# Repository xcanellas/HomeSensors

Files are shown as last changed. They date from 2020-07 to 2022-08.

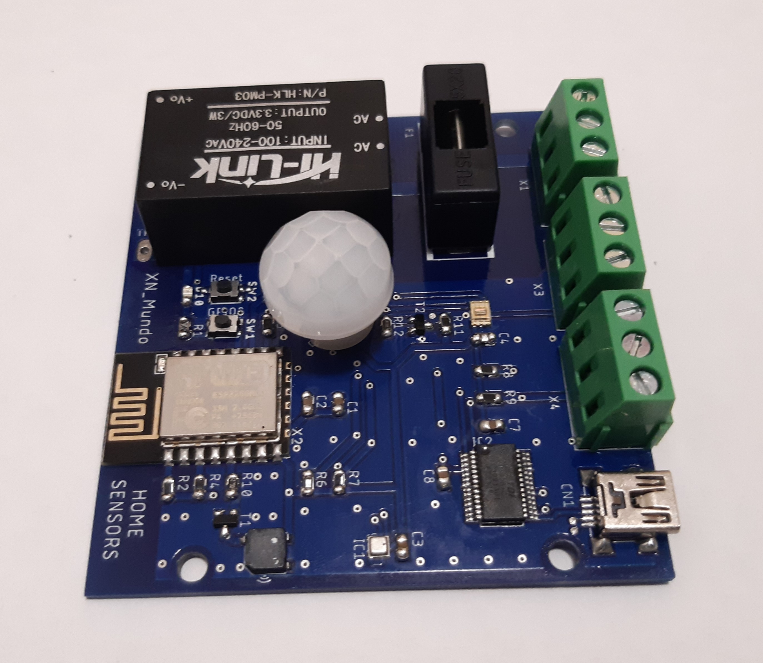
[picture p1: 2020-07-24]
Pictures/HomeSensors.jpg

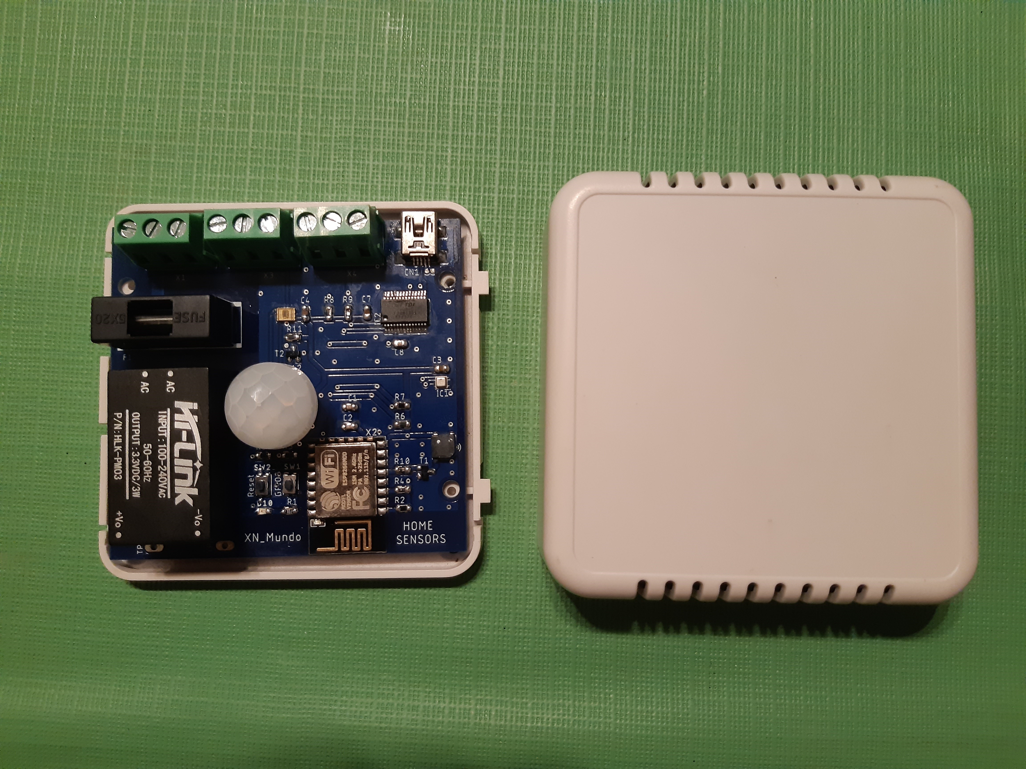
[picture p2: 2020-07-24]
Pictures/HomeSensorsBox.jpg

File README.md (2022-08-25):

## Descripción

Desarrollo de tarjeta electrónica para medir distintos sensores y enviar los datos a traves de WIFI a una base de datos para su posterior tratamiento y visualizacion via WEB.

## Autor
**Xavier Cañellas**

* [Linkedin] (https://www.linkedin.com/in/xcanellas/)
* [Proyectos personales] (http://xnmundo.com/)

## Contacto
Si quieres contactarme puedes escribirme a xcanellas@xnmundo.com para consultas.

## Lincencia
MIT Public License v3.0
No puede usarse comercialmente.

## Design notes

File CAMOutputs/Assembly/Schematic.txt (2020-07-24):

Partlist exported from C:/Users/xcane/Documents/EAGLE/projects/HomeSensors/Schematic.sch at 17/08/2019 17:57

Qty Value        Device                 Package                Parts                               Description                                                                                                                                                                                                                                INTERFACE MF MPN     OC_FARNELL OC_NEWARK SPICEPREFIX TP_SIGNAL_NAME
1                SH22                   SH22                   F1                                  FUSE HOLDER                                                                                                                                                                                                                                                     unknown    unknown                             
1                USBMINIB               USB-MINIB              CN1                                 USB Connectors                                                                                                                                                                                                                                                                                                 
3                W237-03P               W237-133               X1, X3, X4                          WAGO SREW CLAMP                                                                                                                                                                                                                                                 unknown    unknown                             
9   10k          R-EU_M0805             M0805                  R2, R3, R4, R5, R6, R7, R8, R9, R11 RESISTOR, European symbol                                                                                                                                                                                                                                                                                      
1   1k           R-EU_M0805             M0805                  R1                                  RESISTOR, European symbol                                                                                                                                                                                                                                                                                      
6   1uf          C-EUC0805              C0805                  C1, C2, C3, C4, C7, C8              CAPACITOR, European symbol                                                                                                                                                                                                                                                           C                         
1   270          R-EU_M0805             M0805                  R10                                 RESISTOR, European symbol                                                                                                                                                                                                                                                                                      
1   470          R-EU_M0805             M0805                  R12                                 RESISTOR, European symbol                                                                                                                                                                                                                                                                                      
2   BC847        BC847                  SOT23                  T1, T2                              NPN TRANSISTOR                                                                                                                                                                                                                                                                                                 
1   BME280       BME280                 BME280                 IC1                                 DIGITAL HUMIDITY, PRESSURE AND TEMPERATURE SENSOR* Digital interface I²C (up to 3.4 MHz) and SPI (3 and 4 wire, up to 10 MHz)* Supply voltage VDD main supply voltage range: 1.71 V to 3.6 V*VDDIO interface voltage range: 1.2 V to 3.6 V                                                                     
1   D203B        D203B                  3PIN                   PIR1                                                                                                                                                                                                                                                                                                                                               
1   ESP-12       ESP-12                 ESP-12                 X2                                                                                                                                                                                                                                                                                                                                                 
1   FT232RL      FT232RL                SSOP28                 IC2                                 Source: http://www.ftdichip.com/Documents/DataSheets/DS_FT232R_v104.pdf                                                                                                                                                                                 FT232RL 1146032    91K9918                             
1   HLK-PM013W   HLK-PM013W             HLK-PM01               HLK1                                Hi-Link Power Supply                                                                                                                                                                                                                                                                                           
2   KMR2         SWITCH_TACT_SMT4.6X2.8 BTN_KMR2_4.6X2.8       SW1, SW2                            SMT Tact Switches                                                                                                                                                                                                                                                                                              
1   RED          LED0805_NOOUTLINE      CHIPLED_0805_NOOUTLINE D10                                 LED                                                                                                                                                                                                                                                                                                            
1   SMT-0540-S-R SMT-0540-S-R           SMT-0540-S-R           SPK1                                SMT-0549-S-R                                                                                                                                                                                                                                                                                                   
2   TPSQPAD1-13Y TPSQPAD1-13Y           P1-13Y                 TP1, TP2                            Test pad                                                                                                                                                                                                                                                                                                       
1   TSL2561      TSL2561                TMB-6                  U1                                  Texas Instruments                                                                                                                                                                                                                          I2C

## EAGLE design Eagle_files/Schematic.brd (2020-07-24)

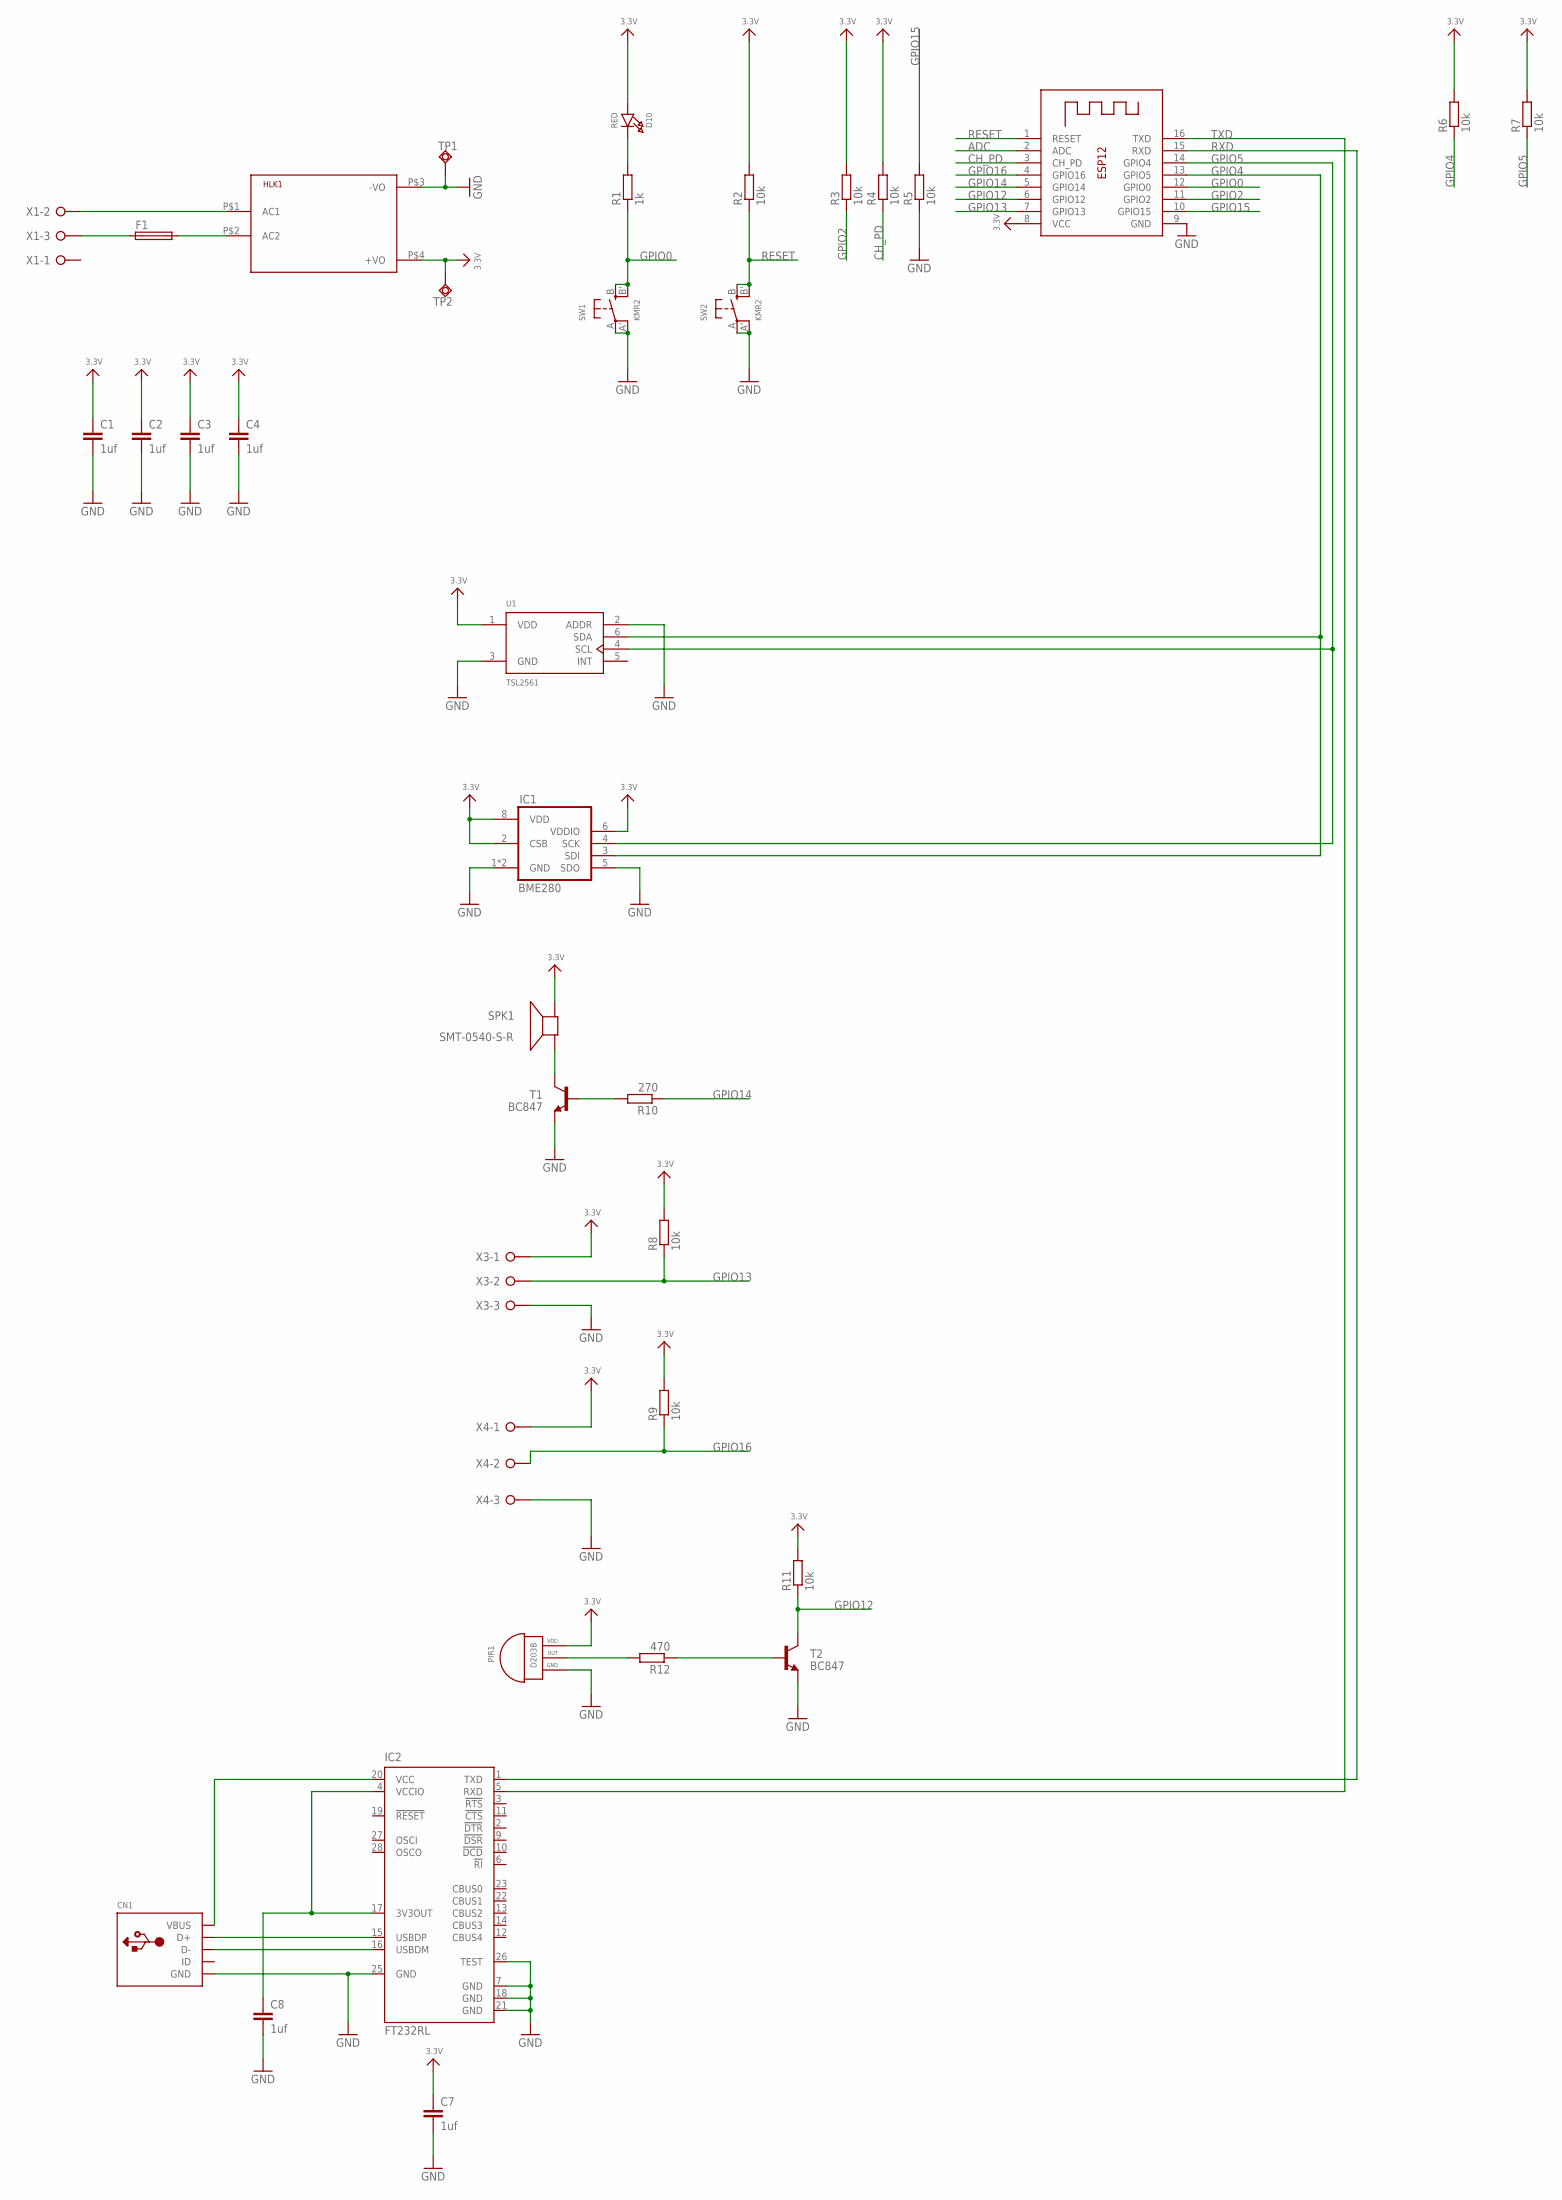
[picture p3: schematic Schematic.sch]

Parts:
C1, C2, C3, C4, C7, C8: 1uf; C0805
CN1: USBMINIB; USB-MINIB
D10: RED; CHIPLED_0805_NOOUTLINE
F1: SH22
HLK1: HLK-PM013W; HLK-PM01
IC1: BME280
IC2: FT232RL; SSOP28
PIR1: D203B; 3PIN
R1: 1k; M0805
R2, R3, R4, R5, R6, R7, R8, R9, R11: 10k; M0805
R10: 270; M0805
R12: 470; M0805
SPK1: SMT-0540-S-R
SW1, SW2: KMR2; BTN_KMR2_4.6X2.8
T1, T2: BC847; SOT23
TP1, TP2: TPSQPAD1-13Y; P1-13Y
U1: TSL2561; TMB-6
X1, X3, X4: W237-03P; W237-133
X2: ESP-12

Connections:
3.3V: C1.1, C2.1, C3.1, C4.1, C7.1, D10.A, HLK1.P$4 (+VO), IC1.2 (CSB), IC1.6 (VDDIO), IC1.8 (VDD), PIR1.1 (VDD), R2.2, R3.2, R4.2, R6.2, R7.2, R8.2, R9.2, R11.2, SPK1.+ (-), TP2.TP, U1.1 (VDD), X2.8 (VCC), X3.1, X4.1
ADC: X2.2 (ADC)
CH_PD: R4.1, X2.3 (CH_PD)
GND: C1.2, C2.2, C3.2, C4.2, C7.2, C8.2, CN1.GND, HLK1.P$3 (-VO), IC1.1 (GND), IC1.5 (SDO), IC1.7 (GND), IC2.7 (GND), IC2.18 (GND), IC2.21 (GND), IC2.25 (GND), IC2.26 (TEST), PIR1.3 (GND), R5.1, SW1.A, SW1.A' (P1), SW2.A, SW2.A' (P1), T1.2 (E), T2.2 (E), TP1.TP, U1.2 (ADDR), U1.3 (GND), X2.9 (GND), X3.3, X4.3
GPIO0: R1.1, SW1.B (S), SW1.B' (S1), X2.12 (GPIO0)
GPIO2: R3.1, X2.11 (GPIO2)
GPIO4: IC1.3 (SDI), R6.1, U1.6 (SDA), X2.13 (GPIO5)
GPIO5: IC1.4 (SCK), R7.1, U1.4 (SCL), X2.14 (GPIO4)
GPIO12: R11.1, T2.3 (C), X2.6 (GPIO12)
GPIO13: R8.1, X2.7 (GPIO13), X3.2
GPIO14: R10.1, X2.5 (GPIO14)
GPIO15: R5.2, X2.10 (GPIO15)
GPIO16: R9.1, X2.4 (GPIO16), X4.2
unnamed: F1.1, X1.3
unnamed: F1.2, HLK1.P$2 (AC2)
unnamed: HLK1.P$1 (AC1), X1.2
unnamed: D10.C, R1.2
unnamed: SPK1.- (+), T1.3 (C)
unnamed: R10.2, T1.1 (B)
unnamed: PIR1.2 (OUT), R12.2
unnamed: R12.1, T2.1 (B)
unnamed: CN1.D+, IC2.15 (USBDP)
unnamed: CN1.D-, IC2.16 (USBDM)
unnamed: C8.1, IC2.4 (VCCIO), IC2.17 (3V3OUT)
unnamed: CN1.VBUS, IC2.20 (VCC)
RESET: R2.1, SW2.B (S), SW2.B' (S1), X2.1 (RESET)
RXD: IC2.1 (TXD), X2.15 (RXD)
TXD: IC2.5 (RXD), X2.16 (TXD)

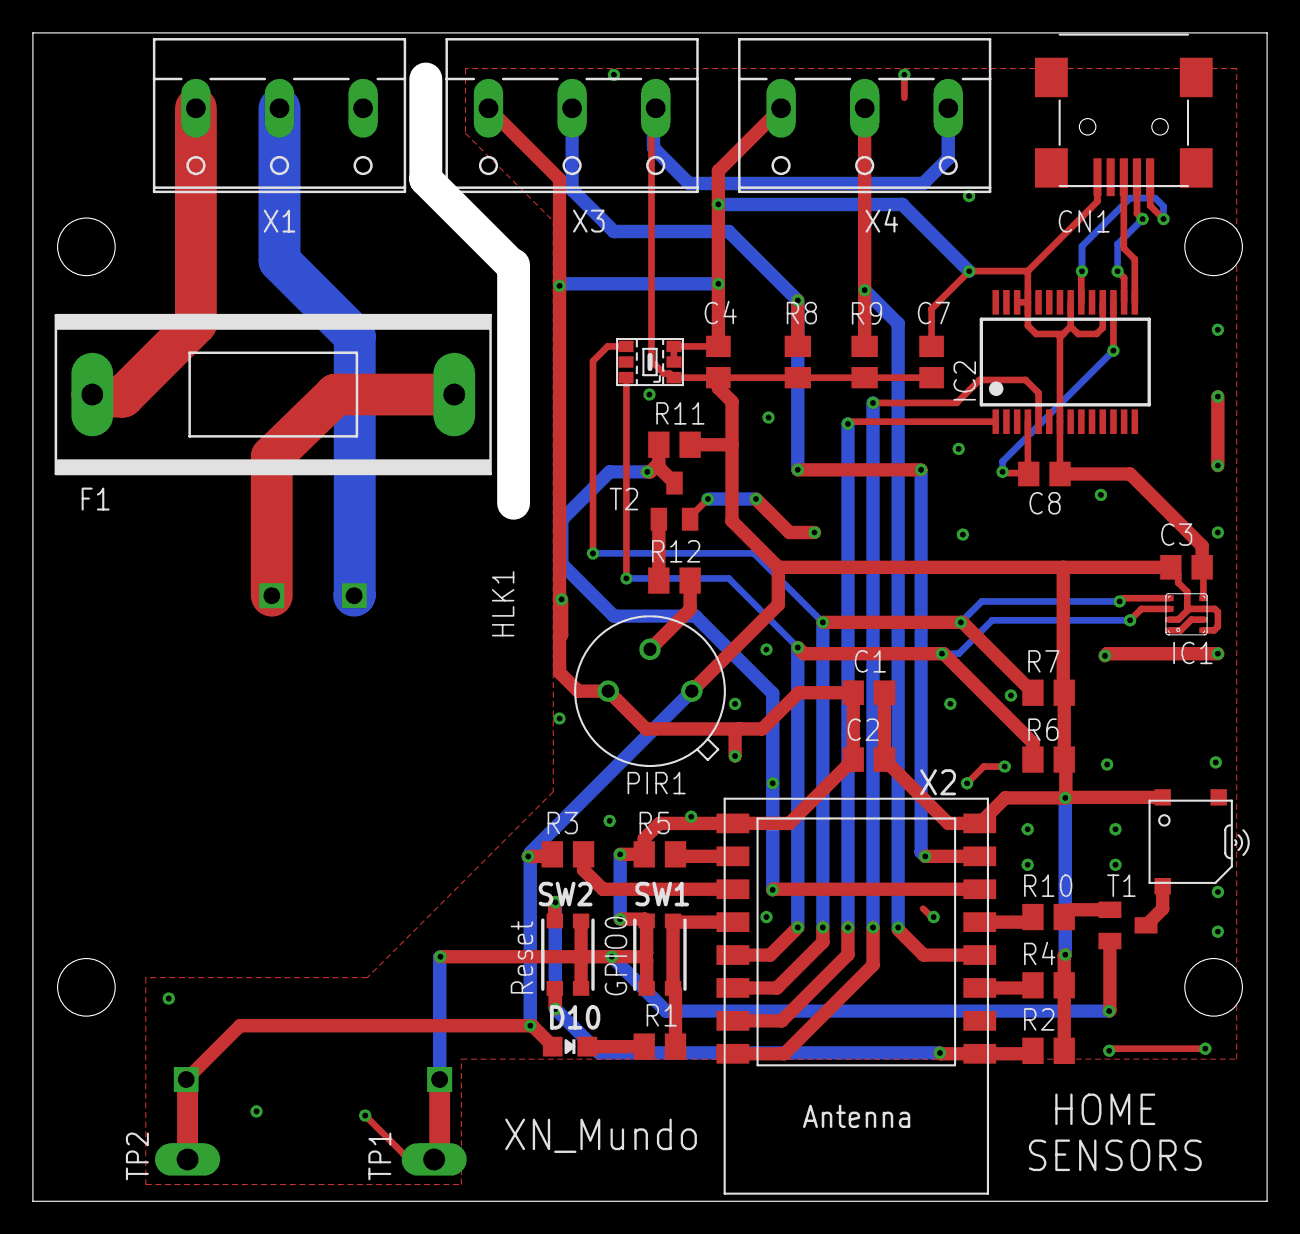
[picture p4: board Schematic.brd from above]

Board: 2 copper layers, 75.0 x 71.0 mm, 37 parts (0 on the bottom side), 27 nets.

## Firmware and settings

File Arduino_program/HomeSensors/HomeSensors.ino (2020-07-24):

#include <Wire.h>
#include <Adafruit_Sensor.h>
#include <Adafruit_TSL2561_U.h>
#include <Adafruit_BME280.h>
#include <ESP8266WiFi.h>
#include <ArduinoOTA.h>

// ESP8266 Number Pins definition
const int Blue_Led = 2;
const int Red_Led = 0;
const int Buzzer = 14;
const int InDig1 = 13;
const int InDig2 = 16;
const int PIR = 12;
const int _SDA = 4;
const int _SCL = 5;

// BME280 SENSOR
#define SEALEVELPRESSURE_HPA (1013.25)
Adafruit_BME280 bme; // I2C
float Temperature;
float Pressure;
float Humidity;
float Altitude;
const float TempCalib = -4.3;

// TSL2561 SENSOR
/*I2C Address
   ===========
   The address will be different depending on whether you leave
   the ADDR pin floating (addr 0x39), or tie it to ground or vcc. 
   The default addess is 0x39, which assumes the ADDR pin is floating
   (not connected to anything).  If you set the ADDR pin high
   or low, use TSL2561_ADDR_HIGH (0x49) or TSL2561_ADDR_LOW
   (0x29) respectively.
*/
   
Adafruit_TSL2561_Unified tsl = Adafruit_TSL2561_Unified(TSL2561_ADDR_LOW, 12345);
float LUX_value;

// Configurar WiFi generada
const char *ssid = "YOUR_WIFI_SSID";
const char *password = "YOUR_WIFI_PASSWORD";

IPAddress ip(IP del displositivo); //Ejemplo 192,168,1,245
IPAddress gateway(IP del router);  //Ejemplo 192,168,1,1
IPAddress subnet(255,255,255,0); 

// Use WiFiClient class to create TCP connections
WiFiClient client;
const int httpPort = 80;
const char* host = "IP del host"; //Ejemplo "192.168.1.245"

// PROGRAM VARIABLES 
bool PIR_temp;
bool InDig1_temp;
bool InDig2_temp;
bool PIR_value;
bool InDig1_value;
bool InDig2_value;
bool Alarma;
bool RefrescaAlarma = false;
int SQLConnectionCounter;
const int SQLConnectionTime = 1800;  //in seconds

void setup() {
  
  // initialize digital pins.
  pinMode(Blue_Led, OUTPUT);
  pinMode(Red_Led, OUTPUT);
  pinMode(Buzzer, OUTPUT);
  pinMode(InDig1, INPUT);
  pinMode(InDig2, INPUT);
  pinMode(PIR, INPUT);

  //Clear Leds Pin
  digitalWrite(Red_Led, HIGH);
  digitalWrite(Blue_Led, HIGH);
  
  Alarma = 0;

  Serial.begin(9600); /* begin serial for debug */

  ConectarWifi();

  ArduinoOTA.setHostname("HomeSensor");
  ArduinoOTA.setPassword((const char *)"xxx"); //Set your OTA password
  ArduinoOTA.begin();

  /* BME280 init */
  if (!bme.begin()) {
    Serial.println("Could not connect to BME280 sensor!");
  }
  else{
    Serial.println("-- BME280 Ready --");
  }

  /* TSL2561 init */
  if(!tsl.begin())
  {
    Serial.print("Could not connect to TSL2561 sensor!");
    while(1);
  }
  else{
    Serial.println("-- TSL2561 Ready --");
  }
  
  /* Configuracion sensor TSL2561 */
  configuracion_TSL2561();
  
  Serial.println();

}


void loop() {

//Gestiona las conexiones vía OTA para programar via WIFI
  ArduinoOTA.handle();

//Comprobamos si hay conexion Wifi
  if(WiFi.status() == WL_DISCONNECTED){
    ConectarWifi();
  }
  
// Leer Sensores de seguridad PIR y puertas
  ReadSafetySensors();
  

// Leer sensores hambientales
  Read_BME280();
  Read_TSL2561();
  

  Serial.println("-------------------------------------------");


    //Conexion al servido SQL cada tiempo SQLConnectionTime
  if(SQLConnectionCounter >= SQLConnectionTime || RefrescaAlarma == true){
    EnviarDatosSQL();
    SQLConnectionCounter = 0;
    RefrescaAlarma = false;
    delay(10000);
  }else{
    SQLConnectionCounter = SQLConnectionCounter + 1;
  }
  
  delay(1000);
  
}



/**************************************************************************************/
/**************************************************************************/
/*Activacion de la alarma*/
/**************************************************************************/
void ActivarAlarma(){
  if(Alarma == false){
    RefrescaAlarma = true;
    Alarma = true;
    BIP_Sonido();               // 3 pitidos de advertencia
  }
  
  digitalWrite(Red_Led, LOW); // Led ROJO ON

}

/**************************************************************************/
/*Desactivacion de la alarma*/
/**************************************************************************/
void DesactivarAlarma(){
  if(Alarma == true){
    RefrescaAlarma = true;
    Alarma = false;
  }
  
  digitalWrite(Red_Led, HIGH); // Led ROJO OFF
  analogWrite(Buzzer, 0);   // Sonido Buzzer OFF  
}

/**************************************************************************/
/*Activación de los tres pitidos de alarma*/
/**************************************************************************/
void BIP_Sonido(){
    analogWrite(Buzzer, 500); delay(150);  // Sonido Buzzer ON
    analogWrite(Buzzer, 0); delay(150);  // Sonido Buzzer OFF
    analogWrite(Buzzer, 500); delay(150);  // Sonido Buzzer ON
    analogWrite(Buzzer, 0); delay(150);  // Sonido Buzzer OFF
    analogWrite(Buzzer, 500); delay(150); // Sonido Buzzer ON
    analogWrite(Buzzer, 0); delay(150);  // Sonido Buzzer OFF
}

/**************************************************************************/
/*Leemos los sensores de seguridad PRESENCIA, PUERTAS*/
/**************************************************************************/
void ReadSafetySensors(){
  // Leer sensores de seguridad
  PIR_value = !digitalRead(PIR);
  InDig1_value = digitalRead(InDig1);
  InDig2_value = digitalRead(InDig2);

    
  if (PIR_value == true|| InDig1_value == true || InDig2_value == true){
    ActivarAlarma();
  }
  else{
    DesactivarAlarma();
  }

  Serial.print("PIR = "); Serial.print(PIR_value);
  Serial.print("  InDig1 = "); Serial.print(InDig1_value);
  Serial.print("  InDig2 = "); Serial.println(InDig2_value);
  
}

/**************************************************************************/
/*Lectura de todas las variables del sensor BME280 PRESION HUMEDAD y TEMPERATURA*/
/*y las mostramos por el puerto serie*/
/**************************************************************************/
void Read_BME280() {

    bme.init();
    Temperature = bme.readTemperature() + TempCalib;
    Humidity = bme.readHumidity();
    Pressure = bme.readPressure() / 100.0F;
    Altitude = bme.readAltitude(SEALEVELPRESSURE_HPA);
    
    Serial.print("Temperature = ");
    Serial.print(Temperature);
    Serial.println(" *C");

    Serial.print("Pressure = ");
    Serial.print(Pressure);
    Serial.println(" hPa");

    Serial.print("Approx. Altitude = ");
    Serial.print(Altitude);
    Serial.println(" m");

    Serial.print("Humidity = ");
    Serial.print(Humidity);
    Serial.println(" %");

}

/**************************************************************************/
/*Configures the gain and integration time for the TSL2561*/
/**************************************************************************/
void configuracion_TSL2561(void){
  /* You can also manually set the gain or enable auto-gain support */
  // tsl.setGain(TSL2561_GAIN_1X);      /* No gain ... use in bright light to avoid sensor saturation */
  // tsl.setGain(TSL2561_GAIN_16X);     /* 16x gain ... use in low light to boost sensitivity */
  tsl.enableAutoRange(true);            /* Auto-gain ... switches automatically between 1x and 16x */
  
  /* Changing the integration time gives you better sensor resolution (402ms = 16-bit data) */
  //tsl.setIntegrationTime(TSL2561_INTEGRATIONTIME_13MS);      /* fast but low resolution */
  tsl.setIntegrationTime(TSL2561_INTEGRATIONTIME_101MS);  /* medium resolution and speed   */
  // tsl.setIntegrationTime(TSL2561_INTEGRATIONTIME_402MS);  /* 16-bit data but slowest conversions */

  /* Update these values depending on what you've set above! */  
//  Serial.println("------------------------------------");
//  Serial.print  ("Gain:         "); Serial.println("Auto");
//  Serial.print  ("Timing:       "); Serial.println("13 ms");
//  Serial.println("------------------------------------");
}

/**************************************************************************/
/*Lecutura del sensor TSL2561*/
/**************************************************************************/
void Read_TSL2561(){
  sensors_event_t event;
  tsl.getEvent(&event);
  LUX_value = event.light;
  /* Display the results (light is measured in lux) */

  Serial.print("Lux = "); Serial.println(LUX_value); 
}

/**************************************************************************/
/*Enviamos todos los datos a la base de datos mediante un PHP*/
/**************************************************************************/
void EnviarDatosSQL(){
  
   if (client.connect(host, httpPort)) {
     Serial.println("SQL Connection done");
     client.print("GET /HomeSensors.php?Temperatura=");
     client.print(Temperature);
     client.print("&");
     client.print("Humedad=");
     client.print(Humidity);
     client.print("&");
     client.print("Presion=");
     client.print(Pressure);
     client.print("&");
     client.print("Altitud=");
     client.print(Altitude);
     client.print("&");
     client.print("Lux=");
     client.print(LUX_value);
     client.print("&");
     client.print("Pir=");
     client.print(PIR_value);
     client.print("&");
     client.print("Door1=");
     client.print(InDig1_value);
     client.print("&");
     client.print("Door2=");
     client.print(InDig2_value);
     client.println(" HTTP/1.0");
     client.println();

     if (!client.connected()) {
      Serial.println();
      Serial.println("disconnecting.");
      client.stop();
    }
  
   }else {
     Serial.println("connection failed");
   }
}

/**************************************************************************/
/*Conexion al wifi*/
/**************************************************************************/
void ConectarWifi(){
  WiFi.mode(WIFI_STA);
  WiFi.config(ip, gateway, subnet);
  WiFi.begin(ssid, password);
  Serial.print("Conectando a:\t");
  Serial.println(ssid); 
 
  // Esperar a que nos conectemos
  while (WiFi.status() != WL_CONNECTED) 
  {
    delay(200); 
    Serial.print('.');
  }
 
  // Mostrar mensaje de exito y dirección IP asignada
  Serial.println("Conexión establecida");  
  Serial.print("IP address:\t");
  Serial.println(WiFi.localIP());
}

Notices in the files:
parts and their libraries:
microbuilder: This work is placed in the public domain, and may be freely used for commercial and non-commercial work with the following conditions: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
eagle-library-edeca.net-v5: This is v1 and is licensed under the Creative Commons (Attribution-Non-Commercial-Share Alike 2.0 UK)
